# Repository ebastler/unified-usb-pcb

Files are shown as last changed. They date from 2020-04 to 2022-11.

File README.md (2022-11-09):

# Unified USB type-C PCB

## Changelog
* 22.11.2020: Simple PCB works, battery PCB is broken. Schematic has been fixed, PCB not. Fix will follow once I find time.
* 09.11.2022: Battery PCB should be fixed, but is untested - I applied the same modifications I previously bodge-wired to earlier protos. The simple PCB now also outputs 5V on the VBUS sense pin, allowing the ZMK Isometria to work with it. I also re-created production files since jlcpcb capabilities increased and they can now assemble everything on these boards. The project is mostly considered abandoned, as I moved to including all battery related circuitry on the main keyboard PCB by now. Still wanted to fix this old project of mine.

A collection of compatible USB-C (2.0) daughterboards with different capabilities, intended to be used in custom mechanical keyboards. All feature the same mechanical dimensions and mounting holes, as well as the same connector leading to the main keyboard PCB and can therefore be exchanged depending on the requeirements.

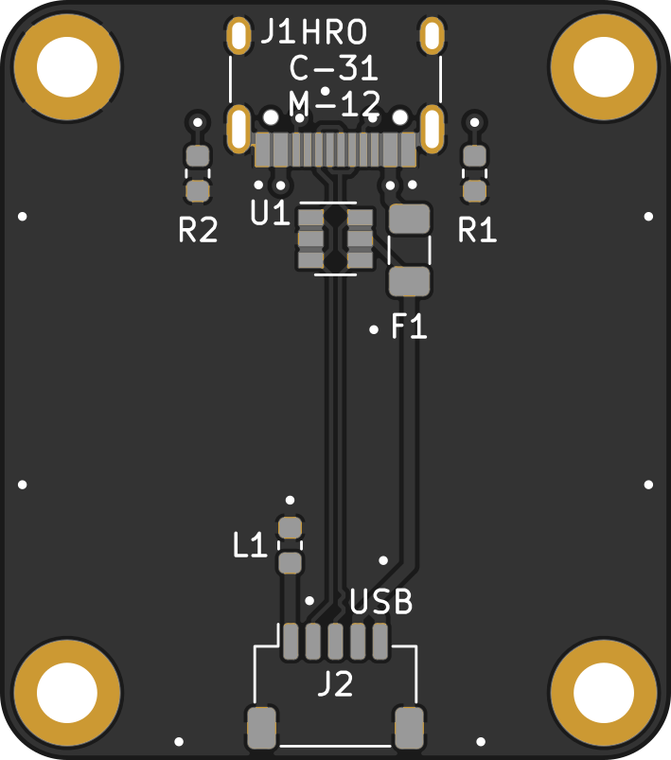
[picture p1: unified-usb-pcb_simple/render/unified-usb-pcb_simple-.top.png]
simple
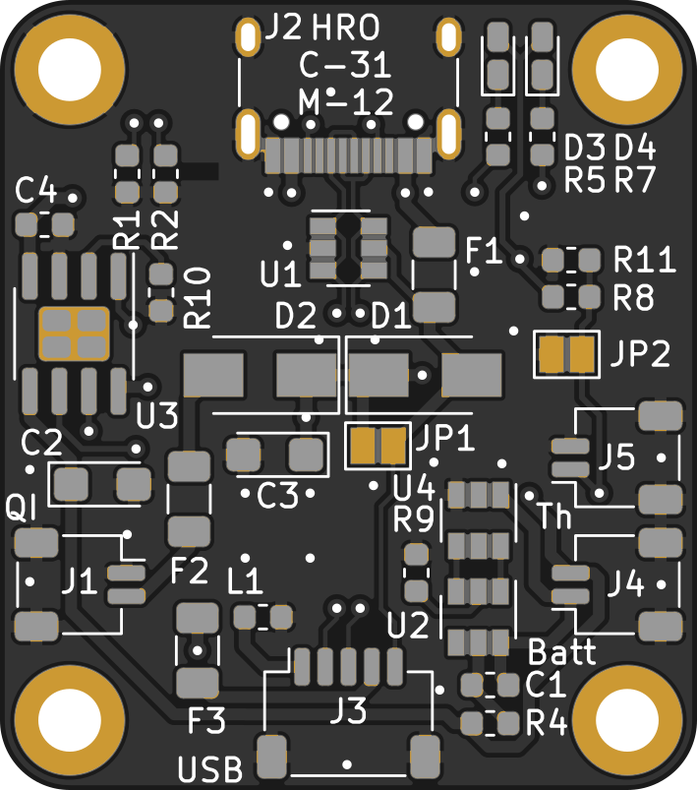
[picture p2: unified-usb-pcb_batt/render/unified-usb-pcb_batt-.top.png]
batt
|||
|:---:|:---:|
|Simple PCB |Battery PCB|

### [Plain USB PCB](unified-usb-pcb_simple)
The simplest and cheapest of the three is just a plain USB breakout board, connecting a USB type C receptacle to a JST SH header for the main keyboard.
 * USB type C
 * SRV-05 TVS on the USB data lines for ESD protection
 * 5 pin JST SH header connecting to the main keyboard PCB

### [Li-Ion PCB](unified-usb-pcb_batt)
This PCB is intended for true wireless use of the keyboard, giving hours of autonomous operation (if a sufficiently large battery is chosen). The battery can be recharged either using the USB-C connector (which can also be used for data) or a QI receiver built into the keyboards base.
 * USB type C
 * JST SH 2-pin input for QI Receiver
 * SRV-05 TVS on the USB data lines for ESD protection
 * JST SH 2-pin header to connect a single Li-Ion or Li-Poly cell
 * TP4056 as a battery charger, DW01 for protection
 * A JST SH 2-pin header allows fo the use of a thermistor to measure cell temperature
 * A sense-wire allows the main controller to check if the battery is currently being charged
 * Solder jumpers to bridge the USB Schottky if no QI receiver is used, as well as the thermistor if the user chooses to use the battery without thermal protection
 * 5 pin JST SH header connecting to the main keyboard PCB

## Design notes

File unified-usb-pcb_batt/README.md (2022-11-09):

# Li-Ion PCB

This PCB is intended for true wireless use of the keyboard, giving hours of autonomous operation (if a sufficiently large battery is chosen). The battery can be recharged either using the USB-C connector (which can also be used for data) or a QI receiver built into the keyboards base.

## Features
 * USB type C
 * JST SH 2-pin input for QI Receiver
 * SRV-05 TVS on the USB data lines for ESD protection
 * JST SH 2-pin header to connect a single Li-Ion or Li-Poly cell
 * TP4056 as a battery charger, DW01 for protection
 * A JST SH 2-pin header allows fo the use of a thermistor to measure cell temperature
 * A sense-wire allows the main controller to check if the battery is currently being charged
 * Solder jumpers to bridge the USB Schottky if no QI receiver is used, as well as the thermistor if the user chooses to use the battery without thermal protection
 * 5 pin JST SH header connecting to the main keyboard PCB

 ## Relevant parts for assembly/customisation

 * Connector J1: QI input, JST SH (SMD, horizontal, 2 Pins. Pin1: GND, Pin2: 5V)
 * Connector J2: USB-C connector (HRO TYPE-C-31-M-12)
 * Connector J3: USB output to main PCB, JST SH (SMD, horizontal, 5 Pins. Pin1: GND, Pin2: D+, Pin3: D-, Pin4: battery voltage, Pin5: charge-sense pin)
 * Connector J4: Battery connector, JST SH (SMD, horizontal, 2 Pins. Pin1: GND, Pin2: Positive)
 * Connector J5: Battery thermistor, JST SH (SMD, horizontal, 2 Pins. Pin1: signal, Pin2: GND (not needed for 3 wire batteries))
 * Jumper JP1: Bridge if no QI is intended to avoid losses over the USB Schottky
 * Jumper JP2: Bridge if you are using an unsupported or no thermistor (the PCB is designed for 10k with a beta of ~ 3500-4000)
 * Switch SW1: Power-switch to cut the battery. [ECE ESP3020](https://www.ece.com.tw/en/switches/slide-switch/56). May be hard to source, but I could not find any similar part that suited this application. Short the 2 pins closer to the JSTs together if you are not using a switch (-> always on).

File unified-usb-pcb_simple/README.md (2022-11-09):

# Plain USB PCB

The simplest and cheapest of the three is just a plain USB breakout board, connecting a USB type C receptacle to a JST SH header for the main keyboard.

## Features
 * USB type C
 * SRV-05 TVS on the USB data lines for ESD protection
 * 5 pin JST SH header connecting to the main keyboard PCB

 ## Relevant parts for assembly/customisation

 * Connector J1: USB-C connector (HRO TYPE-C-31-M-12)
 * Connector J2: USB output to main PCB, JST SH (SMD, horizontal, 5 Pins. Pin1: GND, Pin2: D+, Pin3: D-, Pin4: +5V, Pin5: VBUS detection)

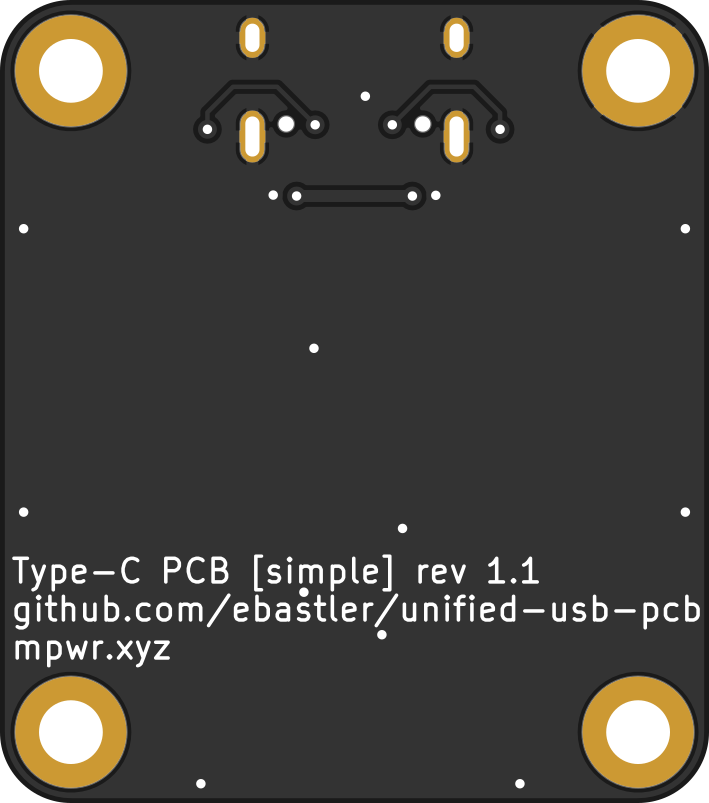
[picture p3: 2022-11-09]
unified-usb-pcb_simple/render/unified-usb-pcb_simple-.bottom.png

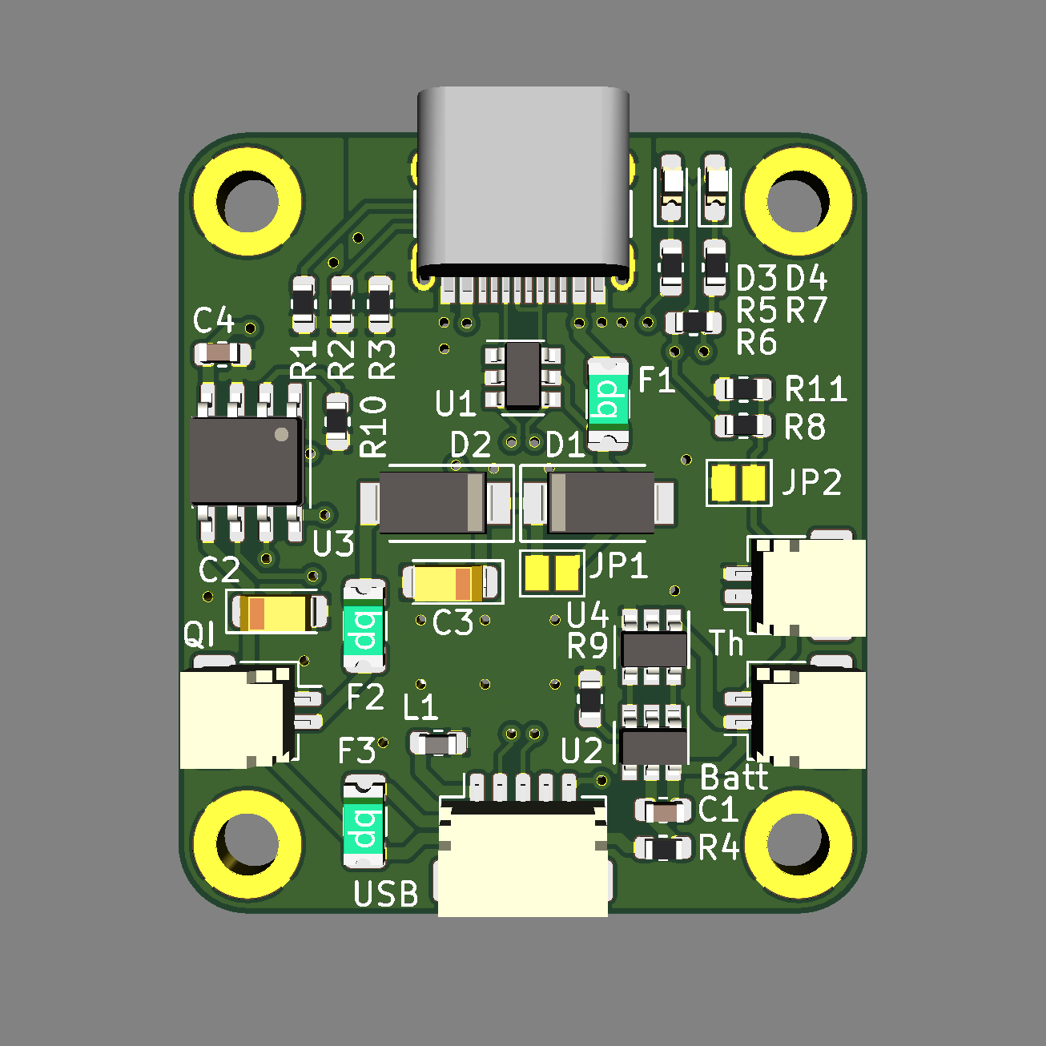
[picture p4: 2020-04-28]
unified-usb-pcb_batt/render/unified-usb-pcb_batt_v1_.png

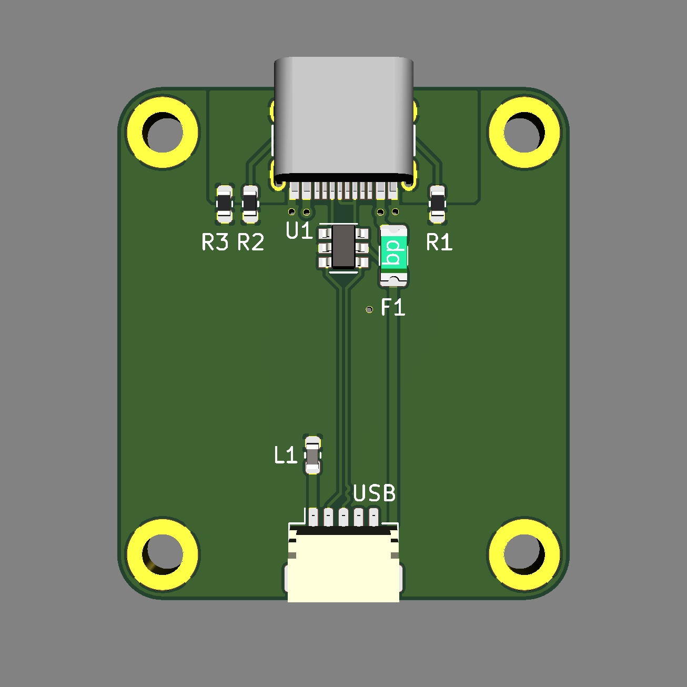
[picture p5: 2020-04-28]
unified-usb-pcb_simple/render/unified-usb-pcb_simple_v1_.png

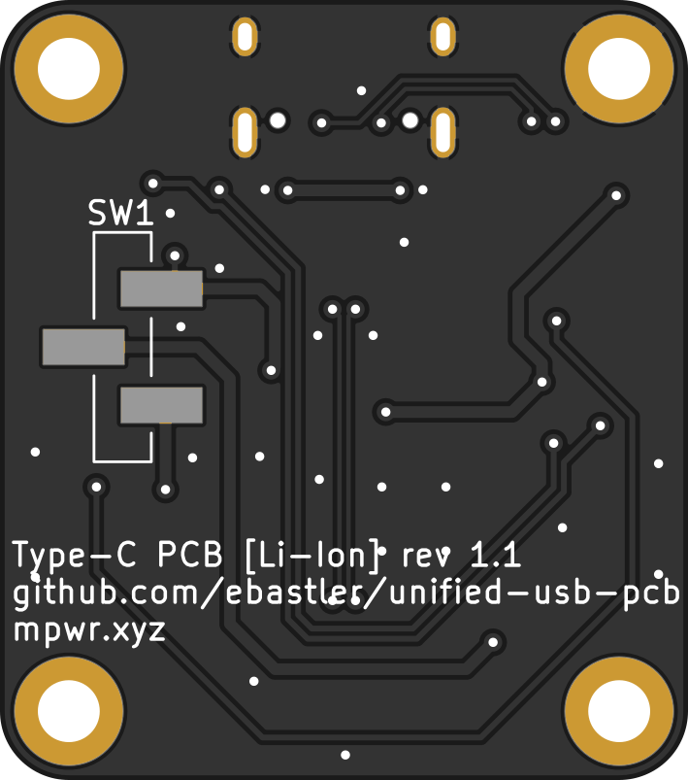
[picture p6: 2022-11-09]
unified-usb-pcb_batt/render/unified-usb-pcb_batt-.bottom.png

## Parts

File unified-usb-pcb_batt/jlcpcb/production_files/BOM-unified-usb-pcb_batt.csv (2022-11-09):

Comment | Designator | Footprint | LCSC
SW_SPDT | SW1 | ESP3020 | /
PBY160808T-181Y-N | L1 | L_0603_1608Metric | C114288
2,7k | R5,R7 | R_0603_1608Metric | C13167
DW01A | U2 | SOT-23-6 | C14213
QI | J1,J4,J5 | JST_SH_SM02B-SRSS-TB_1x02-1MP_P1.00mm_Horizontal | C145954
USB_Out | J3 | JST_SH_SM05B-SRSS-TB_1x05-1MP_P1.00mm_Horizontal | C145957
100n | C1,C4 | C_0603_1608Metric | C14663
TP4056 | U3 | SOIC-8-1EP_3.9x4.9mm_P1.27mm_EP2.29x3mm | C16581
USB_C_Receptacle_USB2.0 | J2 | USB_C_Receptacle_HRO_TYPE-C-31-M-12 | C165948
SCF075-1206R | F1,F2,F3 | Fuse_1206_3216Metric | C20987
1k | R9 | R_0603_1608Metric | C21190
100 | R4 | R_0603_1608Metric | C22775
orange | D4 | LED_0603_1608Metric_Castellated | C2286
3.3k | R8 | R_0603_1608Metric | C22978
5,1k | R1,R2 | R_0603_1608Metric | C23186
22k | R11 | R_0603_1608Metric | C31850
FS8205 | U4 | SOT-23-6 | C32254
1,8k | R10 | R_0603_1608Metric | C4177
10u | C2,C3 | CP_EIA-3216-18_Kemet-A | C7171
green | D3 | LED_0603_1608Metric_Castellated | C72043
SRV05-4 | U1 | SOT-23-6 | C85364
SS34 | D1,D2 | D_SMA | C8678

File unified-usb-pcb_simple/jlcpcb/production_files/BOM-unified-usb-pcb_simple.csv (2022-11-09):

Comment | Designator | Footprint | LCSC
PBY160808T-181Y-N | L1 | L_0603_1608Metric | C114288
USB_Out | J2 | JST_SH_SM05B-SRSS-TB_1x05-1MP_P1.00mm_Horizontal | C145957
USB_C_Receptacle_USB2.0 | J1 | USB_C_Receptacle_HRO_TYPE-C-31-M-12 | C165948
SCF075-1206R | F1 | Fuse_1206_3216Metric | C20987
5.1k | R1,R2 | R_0603_1608Metric | C23186
SRV05-4 | U1 | SOT-23-6 | C85364

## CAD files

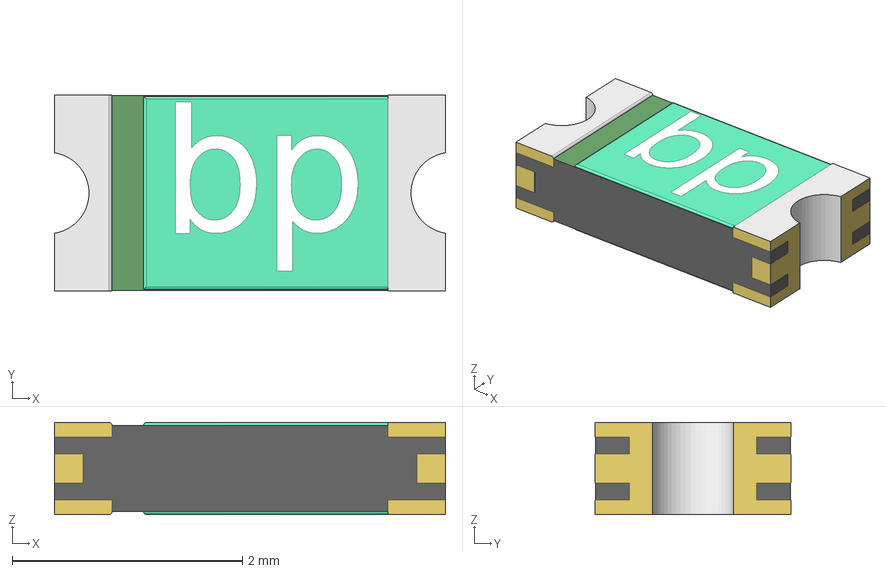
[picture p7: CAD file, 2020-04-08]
3d/0ZCJ0035FF2G.step
3.40 x 1.70 x 0.8 mm

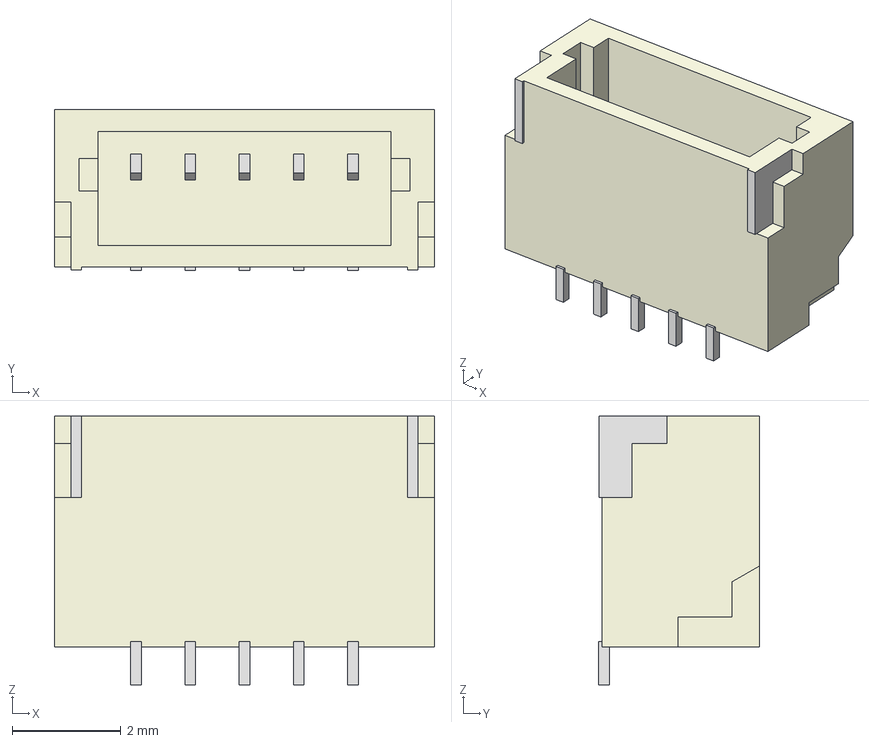
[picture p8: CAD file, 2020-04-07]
3d/SM05B-SRSS-TB.STEP
7.00 x 2.96 x 4.95 mm

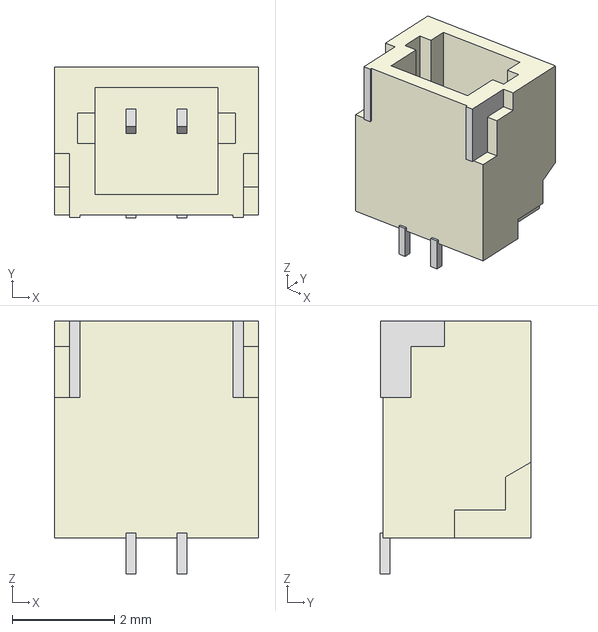
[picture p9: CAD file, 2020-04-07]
3d/SM02B-SRSS-TB.step
4.00 x 2.96 x 4.95 mm

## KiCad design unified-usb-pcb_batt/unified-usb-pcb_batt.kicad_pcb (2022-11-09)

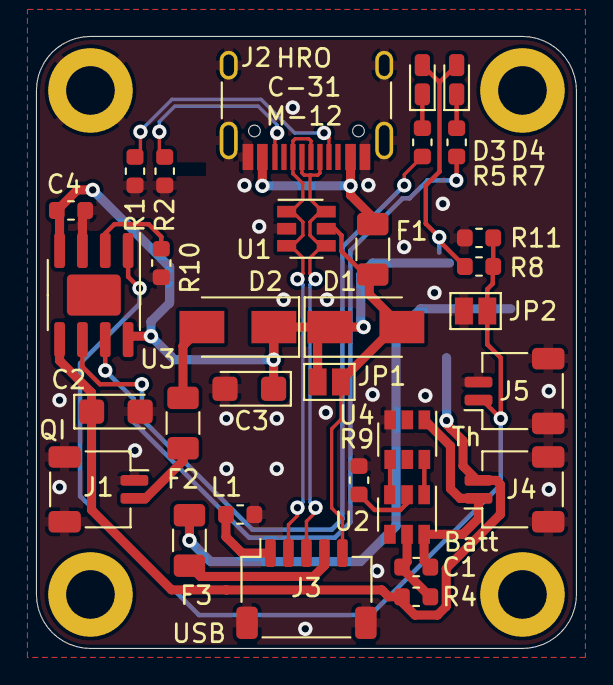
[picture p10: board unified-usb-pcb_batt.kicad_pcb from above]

Board: 2 copper layers, 30.0 x 34.0 mm, 37 parts (1 on the bottom side), 25 nets.

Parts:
C1, C4: 100n; C_0603_1608Metric
C2, C3: 10u; CP_EIA-3216-18_Kemet-A
D1, D2: SS34; D_SMA
D3: green; LED_0603_1608Metric_Castellated
D4: orange; LED_0603_1608Metric_Castellated
F1, F2, F3: SCF075-1206R; Fuse_1206_3216Metric
H1, H2, H3, H4: MountingHole_Pad; MountingHole_2.7mm_M2.5_DIN965_Pad
J1: QI; JST_SH_SM02B-SRSS-TB_1x02-1MP_P1.00mm_Horizontal
J2: USB_C_Receptacle_USB2.0; USB_C_Receptacle_HRO_TYPE-C-31-M-12
J3: USB_Out; JST_SH_SM05B-SRSS-TB_1x05-1MP_P1.00mm_Horizontal
J4: BATT; JST_SH_SM02B-SRSS-TB_1x02-1MP_P1.00mm_Horizontal
J5: THERM; JST_SH_SM02B-SRSS-TB_1x02-1MP_P1.00mm_Horizontal
JP1: No QI; SolderJumper-2_P1.3mm_Open_Pad1.0x1.5mm
JP2: No thermistor; SolderJumper-2_P1.3mm_Open_Pad1.0x1.5mm
L1: PBY160808T-181Y-N; L_0603_1608Metric
R1, R2: 5,1k; R_0603_1608Metric
R4: 100; R_0603_1608Metric
R5, R7: 2,7k; R_0603_1608Metric
R8: 3.3k; R_0603_1608Metric
R9: 1k; R_0603_1608Metric
R10: 1,8k; R_0603_1608Metric
R11: 22k; R_0603_1608Metric
SW1: SW_SPDT; ESP3020
U1: SRV05-4; SOT-23-6
U2: DW01A; SOT-23-6
U3: TP4056; SOIC-8-1EP_3.9x4.9mm_P1.27mm_EP2.29x3mm
U4: FS8205; SOT-23-6

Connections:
+5V: C3.1, C4.1, D1.1 (K), D2.1 (K), D3.2 (A), D4.2 (A), JP1.1 (A), R8.2, SW1.1 (A), U3.4 (VCC), U3.8 (CE)
GND: J3.1, L1.1
GNDPWR: C2.2, C3.2, C4.2, H4.1, J1.1, J1.MP (MountPin), J2.A1 (GND), J2.A12 (GND), J2.B1 (GND), J2.B12 (GND), J2.S1 (SHIELD), J3.MP (MountPin), J4.MP (MountPin), J5.2, J5.MP (MountPin), JP2.2 (B), L1.2, R1.1, R2.1, R9.1, R10.1, R11.1, U1.2 (VN), U3.3 (GND), U4.3 (S2)
unnamed: C2.1, J4.2, R4.2, SW1.3 (C), U3.5 (BAT)
unnamed: D2.2 (A), F2.1
unnamed: D3.1 (K), R5.2
unnamed: D4.1 (K), R7.2
unnamed: F2.2, J1.2
unnamed: F3.1, J3.4
unnamed: F1.2, J2.A4 (VBUS), J2.A9 (VBUS), J2.B4 (VBUS), J2.B9 (VBUS)
unnamed: J2.A5 (CC1), R1.2
unnamed: J2.B5 (CC2), R2.2
unnamed: J5.1, JP2.1 (A), R8.1, R11.2, U3.1 (TEMP)
unnamed: R5.1, U3.6 (STDBY)
unnamed: R7.1, U3.7 (CHRG)
unnamed: R10.2, U3.2 (PROG)
unnamed: U2.1 (OD), U4.6 (G1)
unnamed: R9.2, U2.2 (CSI)
unnamed: U2.3 (OC), U4.4 (G2)
unnamed: C1.1, R4.1, U2.5 (VDD)
unnamed: C1.2, J4.1, U2.6 (VSS), U4.1 (S1)
USB_D+: J2.A6 (D+), J2.B6 (D+), J3.2, U1.1 (IO1), U1.3 (IO2)
USB_D-: J2.A7 (D-), J2.B7 (D-), J3.3, U1.4 (IO3), U1.6 (IO4)
VBUS: D1.2 (A), F1.1, J3.5, JP1.2 (B), U1.5 (VP)
VOUT: F3.2, SW1.2 (B)

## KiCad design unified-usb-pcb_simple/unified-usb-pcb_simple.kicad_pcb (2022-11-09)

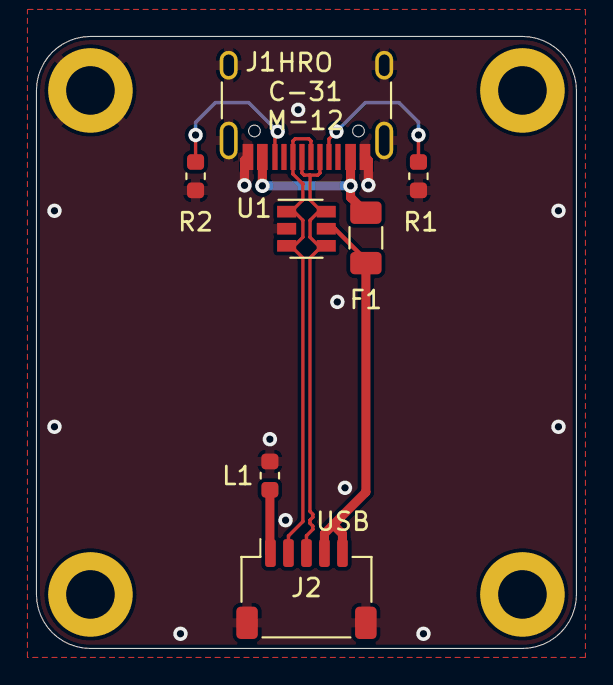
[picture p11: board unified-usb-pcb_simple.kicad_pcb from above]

Board: 2 copper layers, 30.0 x 34.0 mm, 11 parts (0 on the bottom side), 8 nets.

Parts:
F1: SCF075-1206R; Fuse_1206_3216Metric
H1, H2, H3, H4: MountingHole_Pad; MountingHole_2.7mm_M2.5_DIN965_Pad
J1: USB_C_Receptacle_USB2.0; USB_C_Receptacle_HRO_TYPE-C-31-M-12
J2: USB_Out; JST_SH_SM05B-SRSS-TB_1x05-1MP_P1.00mm_Horizontal
L1: PBY160808T-181Y-N; L_0603_1608Metric
R1, R2: 5.1k; R_0603_1608Metric
U1: SRV05-4; SOT-23-6

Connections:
Earth: H1.1, J1.A1 (GND), J1.A12 (GND), J1.B1 (GND), J1.B12 (GND), J1.S1 (SHIELD), J2.MP (MountPin), L1.2, R1.1, R2.1, U1.2 (VN)
GND: J2.1, L1.1
unnamed: F1.2, J1.A4 (VBUS), J1.A9 (VBUS), J1.B4 (VBUS), J1.B9 (VBUS)
unnamed: J1.A5 (CC1), R1.2
unnamed: J1.B5 (CC2), R2.2
USB_D+: J1.A6 (D+), J1.B6 (D+), J2.2, U1.1 (IO1), U1.3 (IO2)
USB_D-: J1.A7 (D-), J1.B7 (D-), J2.3, U1.4 (IO3), U1.6 (IO4)
VOUT: F1.1, J2.4, J2.5, U1.5 (VP)

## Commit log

2020-04-02 partially completed the battery board
    [unified-usb-pcb_batt.kicad_pcb, unified-usb-pcb_batt.sch]
2020-04-03 added thermistor values and charge sense wire
    [unified-usb-pcb_batt.sch]
2020-04-03 added a jumper to disconnect battery
    [unified-usb-pcb_batt.sch]
2020-04-07 continued with Li-Ion schematic, initialised pcb
    [unified-usb-pcb_batt.sch]
2020-04-07 replaced jumper with smd switch
    [unified-usb-pcb_batt.sch]
2020-04-07 added 3d models, changed tp4056 footprint
    [SM02B-SRSS-TB.step, SM05B-SRSS-TB.STEP, unified-usb-pcb_batt.kicad_pcb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]
2020-04-07 added 3d model of switch
    [ESP3020.step]
2020-04-07 added usb-c submodule
    [unified-usb-pcb_batt.kicad_pcb]
2020-04-07 added 3d model for usb-c header
    [unified-usb-pcb_batt.kicad_pcb]
2020-04-07 moved switch 3d model to submodule
    [ESP3020.step, unified-usb-pcb_batt.kicad_pcb]
2020-04-08 started working on pcb layout
    [unified-usb-pcb_batt.kicad_pcb, unified-usb-pcb_batt.sch]
2020-04-08 finished pcb
    [unified-usb-pcb_batt.kicad_pcb, unified-usb-pcb_batt.sch]
2020-04-08 added silkscreen text
    [unified-usb-pcb_batt.kicad_pcb]
2020-04-08 added fuse 3d model
    [0ZCJ0035FF2G.step, unified-usb-pcb_batt.kicad_pcb]
2020-04-08 added readme for LiIon PCB
2020-04-08 cosmetic changes
    [unified-usb-pcb_batt.sch]
2020-04-08 added thermistor recommended value
2020-04-08 created simple usb pcb
    [unified-usb-pcb_simple.kicad_pcb, unified-usb-pcb_simple.sch]
2020-04-08 matched usb trace length
    [unified-usb-pcb_batt.kicad_pcb]
2020-04-08 re-annotaded the schematic
2020-04-08 fixed name on silkscreen
    [unified-usb-pcb_simple.kicad_pcb]
2020-04-08 added ferrite bead, improved usb track matching
    [unified-usb-pcb_simple-B_SilkS.dxf, unified-usb-pcb_simple-F_SilkS.dxf, unified-usb-pcb_simple.kicad_pcb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]
2020-04-08 added ferrite bead
    [unified-usb-pcb_simple.sch]
2020-04-08 removed old silkscreen files
    [unified-usb-pcb_simple-B_SilkS.dxf, unified-usb-pcb_simple-F_SilkS.dxf]
2020-04-15 moved outline/holes for usb-c connector to protrude 1 mm
    [unified-usb-pcb_batt.kicad_pcb, unified-usb-pcb_simple.kicad_pcb]
2020-04-19 moved connectors
    in order to less obstruct underglow less
    [unified-usb-pcb_batt.kicad_pcb]
2020-04-26 created plane for usb-shielding below the connector
    [unified-usb-pcb_simple.kicad_pcb, unified-usb-pcb_simple.sch]
2020-04-26 resized shield plane
    [unified-usb-pcb_simple.kicad_pcb, unified-usb-pcb_simple.sch]
2020-04-26 moved traces for better ground pour, added a probably unneccessary amount of vias
    [unified-usb-pcb_batt.kicad_pcb]
2020-04-26 added jlcpcb part numbers
    [unified-usb-pcb_batt.sch]
2020-04-27 added manufacturing files
    [unified-usb-pcb_simple-B_Cu.gbr, unified-usb-pcb_simple-B_Mask.gbr, unified-usb-pcb_simple-B_Paste.gbr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]
2020-04-27 changed jumper pad, fixed silk
    [unified-usb-pcb_batt.kicad_pcb, unified-usb-pcb_batt.sch]
2020-07-07 changed pcb thickness from 1.6 to 1mm
    [unified-usb-pcb_batt.kicad_pcb, unified-usb-pcb_simple.kicad_pcb]
2020-11-22 fixed batt schem, added readme warning about broken pcb
    [unified-usb-pcb_batt.kicad_pcb, unified-usb-pcb_batt.sch]
2021-02-08 removed chargesense, added VBUS detection to schematic
    [unified-usb-pcb_batt.sch]
2022-11-09 slight rev bump - fixed battery pcb, re-exported new prod files for jlcpcb. Probably last commit, project no longer in active development
    [BOM-unified-usb-pcb_batt.csv, BOM-unified-usb-pcb_simple.csv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]
